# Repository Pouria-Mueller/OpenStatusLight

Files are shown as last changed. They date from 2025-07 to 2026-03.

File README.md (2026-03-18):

# OpenStatusLight

An Open Source Alternative to the "[kuando Busylight](https://busylight.com/)" 

> [!WARNING]
> **This project is still WIP (Work In Progress) and some aspects can change, but it is working** 



## FAQ

#### What do I need?
You can find the Bill of Materials (BOM) [here](https://github.com/Pouria-Mueller/OpenStatusLight/blob/main/BOM/ReadMe.md).

#### Can I modify it?
Yes, modifications are welcome! Just make sure to follow the [license terms](https://github.com/Pouria-Mueller/OpenStatusLight/blob/main/LICENSE).

#### How can I contribute?

Feel free to create a new branch.  
Once you've made your changes, open a Pull Request (PR).  
I'll review it and merge if everything looks good.

<details>
  <summary>Please make sure to verify your commits using a GPG key to ensure authenticity</summary>

  I believe it's good practice to sign your commits to prevent impersonation,  
  so commit signing is **required**.

  If you need more information, here are some helpful links:

  - [GitHub Docs – About Commit Signature Verification](https://docs.github.com/en/authentication/managing-commit-signature-verification/about-commit-signature-verification)  
  - [Unofficial Setup Guide (VS Code)](https://cloudlumberjack.com/posts/setup-github-verified-commits-for-vscode/)

  ---

</details>

#### What platforms are supported?
Currently only Microsoft Teams but I hope I can add support for Matrix, Rocket Chat and maybe Nextcloud and Discord (I don't know about Discord yet, because of recent events), but it highly depends on the API of the platform

### Can I track the status of multiple people?
Yes! that’s actually the main reason I created it. In my workplace, I share a room with two other apprentices. Sometimes, when one of us received a call, the others didn’t notice and accidentally caused interruptions. To solve this, I designed the system to support multiple users and make everyone's status visible in one Light.

## Next Steps

- Adding More Plattforms
- Adding Configuration via Debug Mode 
- Display Mount
- LED-Strip version

## Acknowledgements

 - [README Editor](https://readme.so)
 - [Welcome Werkstatt](https://www.welcome-werkstatt.de/)

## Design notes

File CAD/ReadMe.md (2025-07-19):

# CAD Files

> [!NOTE]
> The Files are Designed to fit the parts listed in the BOM. If you redesign parts you need to follow the License

#### Parts are designed in FreeCAD (/design) but i also exported the .3mf file which is compatible with Slicers if you don´t want to install FreeCAD (/fdm)

>[!WARNING]
>The files are designed for a 0,4mm Nozzle
>I do **not** recommend Dome mode and Variable layer height for the dome!

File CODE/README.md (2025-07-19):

# Installation Guide
## Prerequisites
- Arduino IDE or PlatformIO <- This guide is only for the Arduino IDE
- Connection between the Computer and ESP32
- IO-Pin number for the LEDs
<details>
  <summary>How to find the right IO-Pin</summary>
  

If you don't know what pin you want to use just use Pin 21
</details>

## Installing Dependencies
You need:
- <WiFi.h> Preinstalled
- <HTTPClient.h> Preinstalled
- <ArduinoJson.h> by Benoît Blanchon
- <Adafruit_NeoPixel.h> by AdaFruit
- <TaskScheduler.h> by Anatoli Arkhipenko 

## Connecting ESP32
Connect the ESP-32 via USB(-C) to our computer 
> [!Warning]
> Do not wonder if the Serial monitor gives you weird output before Programming it
> If you get invalid characters after installing Change the BAUD rate to 115200 in the Serial Monitor

On some ESP-32 (Mostly Non-Mini Dev boards) you need to push a (BOOT) Button to enter the Programming mode

## Programming ESP32
Create a New Sketch (CTRL + N) 
Change the Values marked by the Placeholder "ChangeMe" and the LED informations
if you dont know what each value is check the comment above it.

After Programming you may need to press the (EN) Reset button to restart it

## Finishing Setup
After it booted it should start to Glow in Purple which indicates the search for WIFI
if this State does not change after 30 sec check the WIFI Credentials 
> [!Warning]
> All Values including WIFI Name are CASE SENSITIVE

When it connects to the WIFI the lights should turn off and you should get a notification to your webhook which should either return a error if your Application credentials are wrong or a CODE which you need to connect it to your account. 

It only asks for PresenceReadAll permissions to get the Presence value. It can ONLY get Presence and Activity which are by default Publicly accessible.

By default it should now Poll the presence of the User(s) you specified and after and should display by Priority
It goes from Highest to Lowest
Busy Blinking (In call / Presentation / Group Call) > Busy (Calendar Event or Manual Presence) > Available > Away > Offline

## Error Handling
If the light goes blue it is in an error state and a Restart should solve most Problems like session Timeout.
If not one of your credentials might be broken and / or Teams decided to change their api for no Reason

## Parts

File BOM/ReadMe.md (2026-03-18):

# BOM (Bill Of Materials)

All the required parts should be easy to find and affordable.

## Parts
- ESP32 D1 Mini       
- LED Ring (WS2812B) 50mm and/or 37mm
- Wire (Solid Core is easier to solder) ~26AWG should be enough

#### The parts are about 7-10€ from AZ-Delivery

## 3D Print Filament

- Any Base color
- Dome should be **Translucent**

I used Recycled (rPLA) filament from the [Recycling Fabrik](https://recyclingfabrik.com).

Dome: [Milky Glass](https://www.recyclingfabrik.com/products/milchiges-glas-transparent)

Base: [Good Night (Black)](https://www.recyclingfabrik.com/products/gute-nacht-schwarz)

#### If you dont have a 3D printer you can ask your nearest Makerspace if they can print it for you.

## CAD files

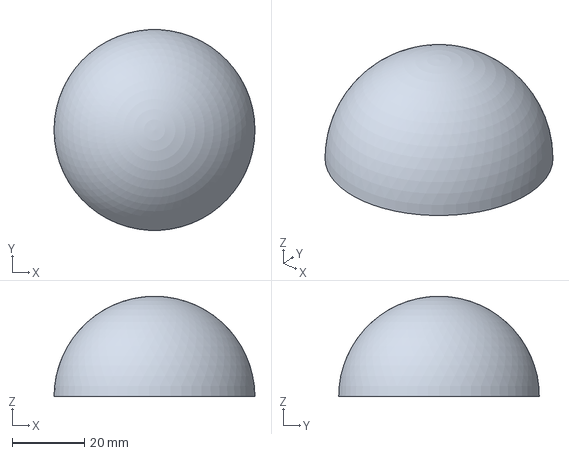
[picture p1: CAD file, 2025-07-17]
CAD/design/OpenStatusLight-Dome.FCStd
55.6 x 55.5 x 27.8 mm

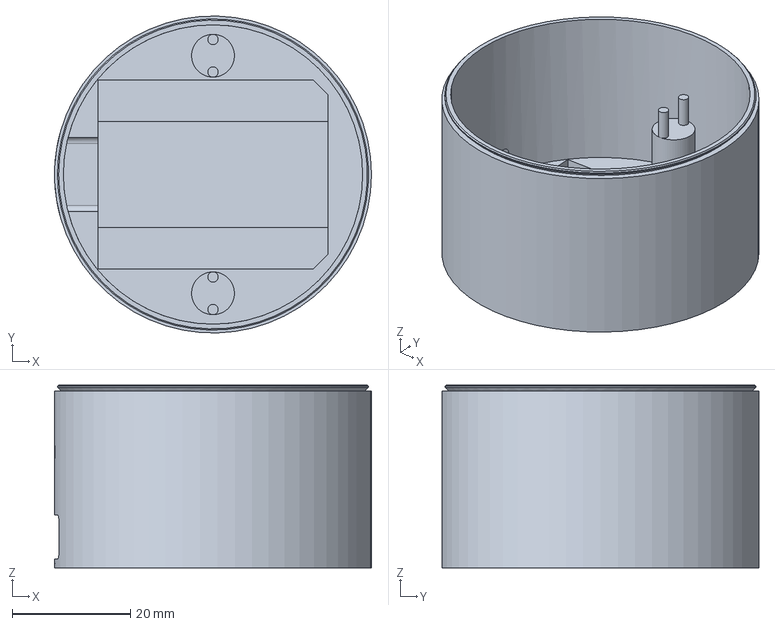
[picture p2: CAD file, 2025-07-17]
CAD/design/OpenStatusLight-Base.FCStd
53.7 x 53.7 x 31.0 mm

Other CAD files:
CAD/fdm/OpenStatusLight-Dome.3mf
CAD/fdm/OpenStatusLight-Base.3mf

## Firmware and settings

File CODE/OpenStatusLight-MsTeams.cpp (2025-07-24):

// Copyright (C) 2025 Pouria Müller
//
// This file is part of OpenStatusLight.
//
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
#include <WiFi.h>
#include <HTTPClient.h>
#include <ArduinoJson.h>
#include <Adafruit_NeoPixel.h>
#include <TaskScheduler.h>
// -----------------------------------------------------------------------------------------------------------------------------------------
// START OF USER CONFIG 

//LED CONFIG
//DATA Pin of ESP32 -- Needs to support PWM - int do not use ["]
#define LED_PIN 21

//Amount of LEDs in Series - int do not use ["]
#define LED_COUNT 24

  
// WEBHOOK CONFIG 
// Discord Example Value: "https://discord.com/api/webhooks/#############/#############"
// Teams only Supports it in Channels (not chats) and is actively pushing to abandon it - USE AT OWN RISK
#define WEBHOOK_URL "ChangeMe"

  
//WIFI CONFIG
//!!!CASE SENSITIVE!!!
//WIFI Name
const char* ssid = "ChangeMe";
//WIFI Password (Supports Spaces if needed)
const char* password = "ChangeMe";


// Microsoft Graph API
// You will need a APP-Registeration ( --NO-- Special Account or Azure Subscription Required) in Azure
// If your Organisation does not allow it write me a pm and/or ask your IT DEPT

// client_id: Application (Client) ID
// Azure / Home / App Registrations
const char* client_id = "ChangeMe";

// client_secret: Secret Value of the Client Key
// Azure / Home / App Registrations -> Manage - Certificates & Secrets (Create a New one) 
const char* client_secret = "ChangeMe";

// tenant_id: Directory (tenant) ID
//  Azure / Home / App Registrations
const char* tenant_id = "ChangeMe";

//USER IDs OF Teams Accounts
// Azure (Entra) / Users -- OR -- Use the API Sandbox https://developer.microsoft.com/en-us/graph/graph-explorer -- LOGIN and use Funktion (GET) user by Email 
// You can enter as many as u want to track (If you share a Room) or just one id -- Seperated by ","
String users[] = {"ChangeMe"}; // {"ChangeMe", "ChangeMe", "ChangeMe"}

// END OF USER CONFIG 
// -----------------------------------------------------------------------------------------------------------------------------------------









String refresh_token = "";
String access_token = "";
Adafruit_NeoPixel strip(LED_COUNT, LED_PIN, NEO_GRB + NEO_KHZ800);
Scheduler runner;  
int numUsers = sizeof(users) / sizeof(users[0]);


// Status Check Task every 15 seconds 
void checkAndSetStatus();
Task statusCheckTask(10000, TASK_FOREVER, checkAndSetStatus);  // YOU CAN MODIFY IT BUT I WOULD NOT RECCOMEND GOING BELOW 5000 (5 sec)


// --- LED Control ---
void setLeds(int status) {
  for (int i = 0; i < LED_COUNT; i++) {
    if (status == 1) strip.setPixelColor(i, strip.Color(255, 0, 0));     // Red (Busy)
    else if (status == 2) strip.setPixelColor(i, strip.Color(0, 255, 0)); // Green (Available)
    else if (status == 3) strip.setPixelColor(i, strip.Color(136, 0, 255)); // Purple (WLAN)
    else if (status == 4) strip.setPixelColor(i, strip.Color(0, 0, 255)); // Blue (Error)
    else if (status == 5) strip.setPixelColor(i, strip.Color(255, 50, 0)); // Orange (AFK)
    else strip.setPixelColor(i, strip.Color(0, 0, 0));  // Off
  }
  strip.show();
}



// --- Presence API Check ---
int checkPresence(String& activityOut) {
  HTTPClient http;
  int highestPriority = 0;
  activityOut = "";

  for (int i = 0; i < numUsers; i++) {
    String url = "https://graph.microsoft.com/v1.0/users/" + users[i] + "/presence";
    http.begin(url);
    http.addHeader("Authorization", "Bearer " + access_token);
    int code = http.GET();
    String res = http.getString();

    if (code == 401) {
      refreshAccessToken();
      http.end();
      return checkPresence(activityOut);
    }

    if (code == 200) {
      DynamicJsonDocument doc(1024);
      DeserializationError err = deserializeJson(doc, res);
      if (!err) {
        String presence = doc["availability"].as<String>();
        String activity = doc["activity"].as<String>();
        if (activity == "InACall" || activity == "InAConferenceCall" || activity == "InAMeeting") activityOut = activity;
        int p = (presence == "Busy") ? 3 : (presence == "Available") ? 2 : (presence == "Away" || presence == "BeRightBack") ? 1 : 0;
        if (p > highestPriority) highestPriority = p;
      }
    }
    http.end();
  }
  return highestPriority;
}

// --- Token-Handling ---
void startDeviceAuth() {
  HTTPClient http;
  http.begin("https://login.microsoftonline.com/" + String(tenant_id) + "/oauth2/v2.0/devicecode");
  http.addHeader("Content-Type", "application/x-www-form-urlencoded");

  String body = "client_id=" + String(client_id) + "&scope=offline_access%20Presence.Read.All";
  int httpResponseCode = http.POST(body);

  if (httpResponseCode == 200) {
    String response = http.getString();
    DynamicJsonDocument doc(1024);
    deserializeJson(doc, response);

    String device_code = doc["device_code"].as<String>();
    String user_code = doc["user_code"].as<String>();
    String verification_uri = doc["verification_uri"].as<String>();

    sendToWebsocket(verification_uri, user_code);
    Serial.println(verification_uri +"  "+ user_code);

    delay(15000);
    pollForToken(device_code);
  } else {
    setLeds(4);
  }
  http.end();
}

void pollForToken(String device_code) {
  HTTPClient http;
  int attempts = 0;
  while (attempts < 30) {
    http.begin("https://login.microsoftonline.com/" + String(tenant_id) + "/oauth2/v2.0/token");
    http.addHeader("Content-Type", "application/x-www-form-urlencoded");

    String body = "client_id=" + String(client_id) + "&client_secret=" + String(client_secret) +
                  "&grant_type=urn:ietf:params:oauth:grant-type:device_code&device_code=" + device_code;

    int httpResponseCode = http.POST(body);

    if (httpResponseCode == 200) {
      String response = http.getString();
      DynamicJsonDocument doc(1024);
      deserializeJson(doc, response);

      access_token = doc["access_token"].as<String>();
      refresh_token = doc["refresh_token"].as<String>();
      http.end();
      return;
    } else {
      String response = http.getString();
      DynamicJsonDocument doc(1024);
      deserializeJson(doc, response);
      String error = doc["error"].as<String>();
      if (error != "authorization_pending") {
        setLeds(4);
        break;
      }
    }
    delay(5000);
    attempts++;
    http.end();
  }
}

void refreshAccessToken() {
  HTTPClient http;
  http.begin("https://login.microsoftonline.com/" + String(tenant_id) + "/oauth2/v2.0/token");
  http.addHeader("Content-Type", "application/x-www-form-urlencoded");

  String body = "client_id=" + String(client_id) +
                "&refresh_token=" + String(refresh_token) + "&grant_type=refresh_token";

  int httpResponseCode = http.POST(body);

  if (httpResponseCode == 200) {
    String response = http.getString();
    DynamicJsonDocument doc(1024);
    deserializeJson(doc, response);
    access_token = doc["access_token"].as<String>();
    if (doc.containsKey("refresh_token")) refresh_token = doc["refresh_token"].as<String>();
  } else {
    setLeds(4);
    sendToWebsocket("ERROR", "TOKEN REFRESH FAILED");
    while (true) delay(60000);
  }
  http.end();
}

// blinking & Task-Handling 
bool blinking = false;
Task blinkTask(100, TASK_FOREVER, []() {
  static int brightness = 0;
  static int direction = 5;  // Fade Steps

  brightness += direction;
  if (brightness >= 255) {
    brightness = 255;
    direction = -5;
  } else if (brightness <= 30) {  // Bottom Threshhold
    brightness = 30;
    direction = 5;
  }

  for (int i = 0; i < LED_COUNT; i++) {
    strip.setPixelColor(i, strip.Color(brightness, 0, 0));  // Red with adapting Brightness
  }
  strip.show();
});

// --- Status Check Logic ---
void checkAndSetStatus() {
  if (WiFi.status() != WL_CONNECTED) return;

  String activity = "";
  int prio = checkPresence(activity);

  if (activity == "InACall" || activity == "InAConferenceCall" || activity == "InAMeeting") {
    if (!blinkTask.isEnabled()) blinkTask.enable();
  } else {
    if (blinkTask.isEnabled()) blinkTask.disable();
    setLeds(prio == 3 ? 1 : prio == 2 ? 2 : prio == 1 ? 5 : 0);
  }
}

// --- websocket Send Message ---
void sendToWebsocket(String verification_uri, String user_code) {
  HTTPClient http;
  http.begin(WEBHOOK_URL);
  String msg = "{\"content\": \"Please open this URL: " + verification_uri + " and enter ```" + user_code + "``` as the code.\"}";
  http.addHeader("Content-Type", "application/json");
  http.POST(msg);
  http.end();
}

void setup() {
  Serial.begin(115200);
  strip.begin();
  strip.show();

  setLeds(3);

  WiFi.begin(ssid, password);
  while (WiFi.status() != WL_CONNECTED) {
    delay(500);
    Serial.print(".");
  }

  Serial.println("\n wifi Connected!");
  setLeds(0);

  if (refresh_token == "") {
    startDeviceAuth();
  } else {
    refreshAccessToken();
  }

  runner.init(); 
  runner.addTask(statusCheckTask);
  runner.addTask(blinkTask);
  statusCheckTask.enable();
}

void loop() {
  runner.execute();  
}

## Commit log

2025-07-16 Updated BOM
    Added Everything
2025-07-17 Added CAD files
    [OpenStatusLight-Base.3mf, OpenStatusLight-Dome.3mf, OpenStatusLight-Dome.FCStd]
2025-07-18 Changed Contribute and Linked busylight dot com (#1)
    * Changed Contribute and Linked busylight dot com
    * Fixed Grammar
    * Fixed Wording
    * Changed Arconym to Full word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
2025-07-19 Create README.md (#2)
    * Create README.md
    Added Guides to setup and Install
    * Update CODE/README.md
    * Update CODE/README.md
    * Update CODE/README.md
    * Update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
2025-07-19 Update ReadMe.md (#4)
    * Update ReadMe.md
    * Update CAD/ReadMe.md
    * Update CAD/ReadMe.md
    ---------
2025-08-01 Changed ToDos
    Changed the plan to implement Config change from BLE/ WIFI to Debug mode via Serial Terminal due to limitations with Simultaneous BLE & WIFI (Same Radio). Decided to detect if its on a PC to add a Console boot mode (Starts only after finishing to prevent creating a Device Code without reason)
2026-03-18 Update BOM link in README

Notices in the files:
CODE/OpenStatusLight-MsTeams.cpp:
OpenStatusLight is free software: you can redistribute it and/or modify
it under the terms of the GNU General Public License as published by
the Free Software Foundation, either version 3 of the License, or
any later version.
